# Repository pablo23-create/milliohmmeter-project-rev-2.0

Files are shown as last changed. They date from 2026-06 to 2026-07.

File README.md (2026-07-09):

# Milliohmmeter

A precision resistance measurement device based on STM32 and INA226,
designed for measuring low-resistance components in the range from µΩ to ~5 Ω.

**Status:** PCB manufacturing

## Overview

This device measures ultra-low resistances using a stabilized pulsed current source.
Pulsed measurement mode prevents resistance drift caused by self-heating of the DUT.

**Typical applications:**
- Transformer and motor winding resistance
- Low-resistance shunts
- PCB via and trace resistance
- Connector and contact resistance

## Hardware

| Component | Description |
|---|---|
| STM32F103C8T6 | Main microcontroller - PWM generation, I2C, measurement control |
| INA226 | High-precision differential current/voltage sensor (I2C) |
| Op-Amp + MOSFET | Stabilized current source |
| SSD1306 | 128×64 OLED display |
| Li-ion cell | Main power source |
| TP4056 / BMS | Battery charging and protection |

**PCB:** 4-layer, designed in Altium Designer

## Measurement Principle

1. MCU generates PWM signal → RC filter converts to DC → voltage divider sets reference
2. Op-amp + MOSFET maintain stable test current through DUT
3. INA226 measures voltage drop across DUT via I2C
4. Resistance is calculated: R = U / I
5. Pulsed mode: current applied briefly, measurement taken at peak, then off
   → eliminates thermal resistance drift
6. 4-wire (Kelvin) connection — separate current injection and voltage
   sensing paths eliminate lead and contact resistance.

## Specifications (target)

| Parameter | Value |
|---|---|
| Measurement range | µΩ - 5 Ω |
| Test current | 100 / 500 / 1000 mA |
| Accuracy | < 1% |
| Display | OLED SSD1306 128×64 |
| Power supply | Li-ion, USB-C 5V charging |
| PCB layers | 4 |

## Status Legend

- [x] Complete
- [~] In progress
- [ ] Planned

## Project Status

- [x] Schematic design
- [x] PCB layout (4-layer)
- [~] PCB manufacturing
- [ ] Firmware development
- [ ] Device calibration and testing
- [ ] Enclosure design (SolidWorks)

## Firmware Architecture

**Toolchain:** STM32CubeIDE, HAL, bare-metal (no RTOS)

**Module structure:**

| File | Responsibility |
|---|---|
| `ina226.c/.h` | INA226 init, register config, voltage read via I2C |
| `ssd1306.c/.h` | OLED display driver |
| `current_source.c/.h` | PWM control, current range selection |
| `measurement.c/.h` | Measurement cycle, averaging, zero calibration |
| `main.c` | Init, superloop |

**Measurement cycle (single reading):**
1. Select current range (100 / 500 / 1000 mA) — auto-selected by result
2. Enable PWM → wait settling time (RC filter + OPA333 loop)
3. Read INA226 voltage across DUT
4. Disable PWM
5. R = U / I

**Zero calibration:**
On startup with probes shorted — measure residual offset, store in Flash, subtract from all subsequent readings.

**Firmware development order:**
1. INA226 driver — verify I2C communication and register reads
2. SSD1306 driver — needed for all subsequent debugging
3. PWM configuration — verify current flow with oscilloscope
4. Measurement cycle assembly
5. Auto-range and zero calibration

## Schematic & PCB

[Schematic and PCB layers (PDF)](hardware/Fabrication.pdf)
[Bill of Materials](hardware/fabrication/Bill%20of%20Materials-111.xlsx)
[PCB 3D renders](photos/)

## Author

**runaway**

## License

MIT License

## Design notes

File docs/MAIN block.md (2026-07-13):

# Main Block — MCU, Power Path, Battery, and System Integration

## Scope

This document covers all hardware subsystems not addressed by the
ADC and DC-DC blocks:

- STM32F103C8T6 microcontroller and pin assignment
- Power-on sequencing (discrete latch: AO3401A + BSS138 + BAT54C)
- Digital 3.3 V LDO (LP5907)
- Li-ion battery system (TP4056 charger, DW01A BMS)
- OLED display (SSD1306)
- USB-C input
- PCB layout, mechanical, and thermal integration

Detailed current-source analysis (OPA333, IRLR7843, INA226 filters)
is in the ADC block. Boost converter design (MT3608, inductor,
output filtering) is in the DC-DC block.

Firmware architecture, calibration procedures, and UI screens are
documented separately in the firmware folder.

## STM32F103C8T6 — Pin Assignment

The MCU is the central controller: it generates PWM, drives I2C
peripherals, manages battery monitoring, and holds the power latch
via PB3 to keep the system powered after button release.

### Active Pin Map

| Pin | Function | Direction | Description |
|---|---|---|---|
| PA7 | ADCBAT | Input | Battery voltage via 100k/330k divider |
| PA8 | PWM_OUT | Output | 100 kHz PWM → RC filter → OPA333 reference |
| PA13 | SWDIO | I/O | SWD programming data, 120 Ω series R |
| PA14 | SWCLK | Input | SWD programming clock, 120 Ω series R |
| PC13 | LED_STATUS | Output | "Firmware is alive" indicator LED |
| PD0 | OSC_IN | Input | HSE crystal pin |
| PD1 | OSC_OUT | Output | HSE crystal pin |
| PB0 | STATUS_CHARGE | Input | 5V-USB presence via 47k/82k divider |
| PB3 | PWR_HOLD | Output | Power latch hold — keeps AO3401A gate low  |
| PB2 | BOOT1 | Input | Boot mode select, 100 kΩ pull-down |
| PB6 | SCL | I/O | I2C clock — INA226, SSD1306 |
| PB7 | SDA | I/O | I2C data — INA226, SSD1306 |
| BOOT0  | BOOT0 | Input | Boot mode select, 100 kΩ pull-down |

### PA7 — Battery Voltage Monitoring (ADCBAT)

Battery voltage is divided to fit the 3.3 V ADC range.
Divider: 100 kΩ (top) / 330 kΩ (bottom) from VBAT to GND.

    V_adc = V_bat × R_bottom / (R_top + R_bottom)
          = V_bat × 330k / (100k + 330k)
          = V_bat × 0.767

Range mapping:
- V_bat = 4.2 V (full) → V_adc = 3.22 V (just under 3.3 V ref)
- V_bat = 3.0 V (cutoff) → V_adc = 2.30 V
- V_bat = 2.5 V (BMS cutoff) → V_adc = 1.92 V

Resistor values are chosen high (430 kΩ total) to minimize
dividing current draw from the battery. A 1 µF X7R capacitor
is placed in parallel with the 330 kΩ (R47) for ADC input
buffering and noise rejection on PCB-level switching events
(at 1.2 MHz from MT3608 a smaller cap is insufficient).

ADC sampling timing: programmed to read ADCBAT once per
measurement cycle, with internal averaging configured
to suppress converter switching noise.

### PA8 — PWM_OUT (100 kHz)

PWM frequency is 100 kHz, generated by TIM1_CH1. The signal feeds
the two-stage RC filter documented in the ADC block; the cutoff
frequency (159 Hz) gives ~-40 dB/dec attenuation of the PWM
fundamental.

Duty cycle is set in firmware to select between 100 mA, 500 mA,
and 1000 mA test current ranges. PWM up-count, center-aligned
mode is supported but not strictly required for RC settling at
this frequency.

### PA13 / PA14 — SWD Programming Header (Debug)

SWDIO and SWCLK lines are routed through 120 Ω series resistors.
This serves two purposes:
- Limits inrush current during programming hot-plug events
- Provides a degree of ESD isolation from external programmers
  before the TVS array settles

A 4-pin SWD header (VCC, SWDIO, SWCLK, GND) is placed on the
board edge. In production these pads are unrouted or covered
with conformal coating if no calibrator access is required.

### PC13 — Firmware Status LED

PC13 is used as a heartbeat indicator. The LED is driven low-active
(opens when the firmware loop is running). It is intentionally
NOT a power indicator — power state is visible via the OLED.

Series R = 1 kΩ with a standard red LED (V_F ≈ 2.0 V, I_F ≈ 1 mA):

    I_F = (3.3 - 2.0) / 1k = 1.3 mA

PC13 has the limitation that the LED remains in an
"inconsistent" state during and after reset, but for this
project on-board reset is not a user-visible event — the
100 ms lamp test during boot is acceptable.

### PD0 / PD1 — HSE Crystal (8 MHz)

External 8 MHz HSE crystal drives the PLL to produce the
72 MHz SYSCLK. Crystal load capacitor selection:

    C_load = 2 × (C_L − C_stray) = 2 × (20pF − 5pF) = 30 pF

C17 = C18 = 30 pF (C0G/NP0 dielectric).

HSE is preferred over the internal HSI (±1% accuracy) because
PWM frequency error at ±1% directly maps to test current error
of ±1% — at µΩ measurement levels this dominates accuracy budget.

The crystal is placed close to the OSC pins with a guarded
GND loop around it to prevent 1.2 MHz MT3608 switching noise
from coupling into the oscillator load capacitance.

Note: on the LQFP48 package, PD0/PD1 are the only pins usable
as OSC_IN/OSC_OUT for HSE — they cannot be repurposed as GPIO
in this package. PC14/PC15 are OSC32_IN/OSC32_OUT (LSE, 32.768
kHz) and are unused here since this design has no RTC crystal.

### PB0 — USB Power Detect (STATUS_CHARGE)

PB0 reads the presence of 5 V on USB-C VBUS through a
47 kΩ / 82 kΩ divider.

    V_pb0 = 5.0 × 82k / (47k + 82k) = 5.0 × 0.636 = 3.18 V

This sits below 3.3 V MCU supply and is directly read as a
GPIO high → "USB connected" condition. Reverse-biased action
is not relevant — the divider is unconditionally high impedance
and draws < 100 µA from VBUS even when the device is off.

STATUS_CHARGE is sampled by the firmware to enable battery
voltage display mode on OLED and to detect charging cycles.

### PB3 — Power Latch Hold (PWR_HOLD)

PB3 controls the discrete power latch that keeps the system powered
after the user releases the power button.

**Latch circuit (replaces LTC2954):**
- SW1 (power button) pulls the gate of Q1 (AO3401A, P-channel) to GND
  on press, turning Q1 on and powering the system
- BSS138 (N-channel MOSFET) gate is driven by PB3 via a 1 kΩ
  series resistor; BSS138 source-gate has a 1 kΩ pull-down to GND
- BAT54C dual Schottky diode assembly: one diode from SW1, one from
  BSS138 drain, both feeding Q1 gate — OR-logic, either can hold
  Q1 gate low independently

**Power-on sequence:**
1. User presses SW1 → Q1 gate pulled to GND via SW1 → Q1 conducts
   → MT3608 boost starts → LDOs come up → STM32 boots
2. STM32 firmware initializes → drives PB3 HIGH within first 100 ms
   → BSS138 turns on → holds Q1 gate low via BAT54C
3. User releases SW1 → system remains powered via BSS138 latch

**Power-off sequence:**
1. User presses SW1 again (or firmware initiates shutdown)
2. Firmware drives PB3 LOW → BSS138 turns off
3. Q1 gate released → Q1 turns off → system powers down

This is a fully discrete implementation with no dedicated power
controller IC. Shutdown is always firmware-initiated — there is no
hardware watchdog timeout as with LTC2954. IWDG should be used
as the primary fault recovery mechanism.

### PB2 / BOOT0 — Boot Mode Selection

Both PB2 (BOOT1) and BOOT0 are pulled down to GND via 100 kΩ
resistors, selecting boot from internal flash (BOOT1 = 0,
BOOT0 = 0).

The 100 kΩ value is standard practice when no external boot
source is connected — it draws no DC current except negligible
leakage and pulls the line to a defined state even if the SWD
header is floating.

### PB6 / PB7 — I2C Bus (Standard Mode)

I2C1 operates at Standard Mode (100 kHz) — sufficient for
INA226 (512 conversions/sec) and SSD1306 refresh rates.

Pull-ups are 4.7 kΩ to 3.3 V on both SCL and SDA. Selected
per I2C specification for Standard Mode:

    R_min = (V_cc − V_ol_max) / I_ol = (3.3 − 0.4) / 3mA = 967 Ω
    R_max = 1000 ns / (C_bus + C_pins) ≈ 10 kΩ at 100 kHz

A 4.7 kΩ midpoint value gives clean edges with the
combined bus capacitance of INA226 + SSD1306 + trace
(estimated C_bus < 50 pF).

If firmware debugging reveals timing-dependent issues
during long cable I2C runs to the OLED, switching to Fast
Mode (400 kHz) with 2.2 kΩ pull-ups is a trivial firmware-side
change with no hardware rework required.

## Power-On Controller — Discrete Latch (AO3401A + BSS138 + BAT54C)

The discrete latch replaces a dedicated power controller IC (previously LTC2954).
The MCU cannot latch its own supply directly — once the user releases the button,
VBAT to the boost converter would drop. The latch holds Q1 gate low after boot
until firmware explicitly releases it.

### Sequencing

1. User presses SW1 (≥ ~50 ms debounce in firmware) →
   Q1 (AO3401A) gate pulled to GND via SW1 + BAT54C →
   Q1 conducts → MT3608 boost starts → LP2985 / LP5907 come up → STM32 boots
2. STM32 firmware initializes → drives PB3 HIGH within first 100 ms →
   BSS138 turns on → holds Q1 gate low via BAT54C → latch engaged
3. User releases SW1 → system remains powered via BSS138

### Shutdown

Firmware drives PB3 LOW → BSS138 turns off → Q1 gate released → system powers down.

Power-off is always firmware-initiated. No hardware kill timer exists.
IWDG is the primary fault recovery path — on timeout, reset handler
must drive PB3 LOW before re-entering the main loop or halting.

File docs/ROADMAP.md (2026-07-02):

# Project Documentation Roadmap

## Status Legend
- [x] Complete
- [~] In progress
- [ ] Planned

---

- [x] ADC Block (OPA333, RC-filter, INA226, LP2985)
- [x] DC-DC Block
- [x] Main Block
- [~] Firmware
- [ ] Debug & Testing
- [ ] Future Improvements

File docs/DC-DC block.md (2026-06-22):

# DC-DC Block — MT3608 Boost Converter

## Overview

The DC-DC block steps up the Li-ion battery voltage to a regulated 5.5 V rail,
which feeds downstream LDO regulators:

- **LP5907 3.3 V** — digital supply (STM32, SSD1306)
- **LP2985 5 V** — clean analog supply (OPA333)

Using 5.5 V as the boost target instead of 5.0 V provides 520 mV of headroom
for the LP2985 LDO (dropout ~30 mV) and ensures stable output across the full
Li-ion discharge range (3.0 V – 4.2 V).

The boost output is enabled via Q1 (AO3401A, P-channel MOSFET) controlled
by the EN signal from LTC2954 power-on controller.

## Component Selection

### MT3608 — Boost Controller

| Parameter | Value |
|---|---|
| Topology | Boost (PWM) |
| Switching freq. | 1.2 MHz (internal osc) |
| V_ref (FB) | 0.6 V |
| SW current limit  | 4 A |
| V_in range | 2.0 V – 24 V |
| Package | SOT-23-6 |

1.2 MHz switching frequency is the key design constraint for this project.
All analog measurements (INA226, OPA333 loop) must be protected from
switching noise at this frequency — addressed in the ADC block via
LP2985 isolation and RC filters on INA226 inputs.

### Power Switch — AO3401A (Q1)

P-channel MOSFET controlled by EN signal from LTC2954. Connects VBAT to
the MT3608 input when EN is asserted. R29/R30 (100 kΩ / 100 kΩ) form a
gate voltage divider to ensure reliable turn-on/turn-off.

### Inductor — Bourns SRP5030T-4R7M (L1)

| Parameter | Value |
|---|---|
| Inductance | 4.7 µH |
| I_sat | 6 A |
| I_rms | 5 A |
| DCR | ~27 mΩ |
| Package | 5.0×5.0 mm  |
| Shielding | Yes |

**Why 4.7 µH:**
At 1.2 MHz switching frequency, a smaller inductance is sufficient to
maintain continuous conduction mode (CCM) without excessive ripple current.

Duty cycle at V_in = 3.7 V:

    D = 1 - V_in / V_out = 1 - 3.7 / 5.5 = 0.327

Inductor ripple current:

    dI_L = (V_in x D) / (L x f_sw)
         = (3.7 x 0.327) / (4.7uH x 1.2MHz)
         = 1.21 / 5.64
         = 0.215 A

Ripple dI_L = 215 mA — well within acceptable range.

**Peak current at maximum load (1.2 A):**

    I_peak = I_out x (V_out / (V_in x eta)) + dI_L / 2
           = 1.2 x (5.5 / (3.7 x 0.85)) + 0.108
           = 2.10 + 0.11
           = 2.21 A

I_sat = 6 A provides a safety margin of 2.7x at full load.

**MT3608 current limit verification:**

    I_out_max = (I_sw_max - dI_L / 2) x V_in x eta / V_out
              = (4 - 0.108) x 3.7 x 0.85 / 5.5
              = 2.25 A

1.2 A load is within MT3608 capability with ~1.9x margin.

**Why shielded:**
The SRP5030T series uses a closed magnetic core. This suppresses fringing
flux that would otherwise couple into the L2 solid GND plane and propagate
switching noise across the board — critical given the µΩ-level measurements
in the ADC block.

### Feedback Divider (R2 / R3)

Output voltage is set by a resistive divider on the FB pin:

    V_out = V_ref x (1 + R2 / R3)

With V_ref = 0.6 V and target V_out = 5.5 V:

    R2 / R3 = V_out / V_ref - 1 = 5.5 / 0.6 - 1 = 8.167

Choosing R3 = 100 kΩ:

    R2 = 100k x 8.167 = 816.7 kΩ  →  820 kΩ (E24 series)

Verification:

    V_out = 0.6 x (1 + 820k / 100k) = 0.6 x 9.2 = 5.52 V

Error: +0.4% — acceptable. The 5.5 V target is a headroom rail, not a
precision reference.

> **Note:** Use 1% tolerance resistors for the feedback divider.
> 5% resistors introduce up to ±0.5 V error on V_out — sufficient to
> drop LP2985 input below its minimum or exceed downstream component
> absolute maximum ratings.

### Rectifier Diode — SS36AHL (D1)

| Parameter | Value |
|---|---|
| Type | Schottky |
| V_R (reverse) | 60 V |
| I_F (avg) | 3 A |
| V_F at 1 A | ~0.5 V |
| Package | DO-214AB |

SS36AHL is an improved variant of SS36 with lower reverse leakage current
and better thermal stability. V_R = 60 V exceeds worst-case voltage spikes
(V_out + switching ringing) with margin. Handles full load current of
1.2 A with 2.5x headroom.

### Output Capacitor — C3, 22 µF Ceramic (X8R)

| Parameter | Value |
|---|---|
| Capacitance | 22 µF (nominal) |
| Dielectric | X8R |
| Voltage rating | ≥ 10 V recommended  |

**Why ceramic over electrolytic:**
Ceramic capacitors have very low ESR, which reduces output voltage ripple
at 1.2 MHz. Electrolytic capacitors have significantly higher ESR at this
frequency and are less effective at filtering switching noise.

**DC bias derating:**
Ceramic capacitors lose effective capacitance under DC bias voltage.
The MT3608 datasheet reference design specifies 22 µF nominal but does
not account for derating at operating voltage.

At 5.5 V DC bias, the 22 µF X8R capacitor degrades to approximately
~4.4 µF effective capacitance (~80% loss).

Impact on output voltage ripple at maximum load (1.2 A):

    dV_out = (I_out x D) / (C_eff x f_sw)
           = (1.2 x 0.327) / (4.4uF x 1.2MHz)
           = 0.392 / 5.28
           = 74.8 mV

For comparison, at nominal 22 µF without derating:

    dV_out = (1.2 x 0.327) / (22uF x 1.2MHz) = 14.9 mV

Derating increases ripple by 5x. At 1.2 A load this is significant —
74.8 mV ripple on the 5.5 V rail reduces the effective headroom for
LP2985 from 520 mV to ~445 mV under worst case. LP2985 (PSRR = 75 dB
at 1.2 MHz) attenuates this ripple by ~5600x before it reaches the
analog supply, so measurement accuracy is not compromised. However,
adding a second output capacitor is recommended.

**Recommended fix — add second 100 µF X8R in parallel:**

    C_eff_total = 4.4 + 19 = 23.4 uF
    dV_out = (1.2 x 0.327) / (23.4uF x 1.2MHz) = 13,9 mV

Ripple reduced by 2x with minimal board area impact (same footprint).

**INA226 averaging as supplementary ripple mitigation:**
The INA226 ADC supports hardware averaging (up to 1024 samples).
This is used as a supplementary measure alongside output capacitor
filtering — averaging reduces the effect of residual switching noise
on voltage measurements, improving effective resolution at µΩ levels.
Averaging does not replace output filtering but complements it.

X8R was selected over X5R/X7R for better DC bias stability.

### Input Capacitor — C1, 22 µF Ceramic

C1 provides local decoupling at the MT3608 input, stabilizing V_in
during switching transients and reducing input ripple current drawn
from the battery.

## PCB Layout Considerations

The MT3608 switching loop carries high di/dt currents at 1.2 MHz.
Poor layout directly causes noise coupling into analog measurements.

**Critical loop:** MT3608 SW pin → L1 → D1 → C3 → GND → MT3608 GND

- Keep this loop as small as possible on L1 signal layer
- Place C3 immediately adjacent to D1 cathode and MT3608 output
- SW node trace must be short and wide — it carries full inductor current
- Do not route sensitive analog signals parallel to the SW node trace

**Component placement:**
The DC-DC block (Q1, U2, L1, D1) is located in the top-left corner of
the board. The analog measurement block (OPA333, INA226) is located on
the right edge, with STM32 between them. This physical separation
minimizes direct coupling of switching noise into the analog section.

**GND plane (L2):**
The board uses a single solid GND plane on L2 without a separate analog
ground pour. This is acceptable given the physical separation between
the DC-DC and analog blocks — switching return currents follow the
path of least impedance back to Q1/U2 and do not pass through the
analog measurement zone.

The shielded inductor (SRP5030T) prevents magnetic flux from coupling
into the GND plane beneath it.

**LP2985 placement:**
LP2985 sits between the 5.5 V boost rail and the OPA333 analog supply.
Its 75 dB PSRR at 1.2 MHz is the primary isolation barrier for the
analog block. Placement close to OPA333 minimizes post-regulation
trace length and reduces pickup area.

## Power Budget

| Rail | Consumer | Estimated Current |
|---|---|---|
| 3.3 V (LP5907) | STM32 | ~50 mA |
| 3.3 V (LP5907) | SSD1306 OLED | ~20 mA |
| 5 V (LP2985) | OPA333 | ~5 mA |
| 5.5 V | LDO quiescent + misc | ~5 mA |
| 5.5 V | Current source (DUT) | ~1100 mA (peak) |
| **Total** | | **~1180 mA** |

Peak load occurs only during measurement pulses (~100 ms). Average
current draw is significantly lower due to the pulsed measurement mode.

MT3608 maximum deliverable output current at V_in = 3.7 V:

    I_out_max = (I_sw_max - dI_L / 2) x V_in x eta / V_out
              = (4 - 0.108) x 3.7 x 0.85 / 5.5
              = 2.25 A

1.2 A peak load leaves ~1.05 A margin.

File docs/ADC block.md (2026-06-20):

# ADC Block - Technical Design Document

## OPA333 - Current Source Control

OPA333 was selected for its near-zero input offset voltage (zero-drift),
rail-to-rail input/output, and wide input voltage range.
These characteristics are critical for precise reference voltage
reproduction at the op-amp input, which directly controls
the test current stability.

## PWM-to-Reference Conversion (RC Filter)

MCU generates PWM signal which is converted to a stable DC reference
voltage for the op-amp via a two-stage RC filter.

**Filter parameters (each stage):**
- R = 10 kΩ, C = 100 nF
- Cutoff frequency: f = 1/(2π·R·C) ≈ 159 Hz

Two identical cascades do not shift the cutoff frequency —
it remains at 159 Hz — but increase the roll-off slope
from -20 dB/dec to -40 dB/dec, significantly improving
PWM ripple suppression at 100 kHz.

**Settling time:**
- Single stage: 5τ = 5·RC = 5 ms
- Two stages: approximately 12–13 ms (empirical ~2.5× factor)

PWM frequency of 100 kHz ensures fast RC settling,
allowing pulsed measurement duration to be reduced if needed
by increasing PWM frequency — shorter settling time means
shorter minimum pulse width.

## Voltage Divider (Post-Filter)

A 10:1 voltage divider is placed after the two-stage RC filter.

This serves two purposes:
- Scales the reference voltage to the required input range of OPA333
- Reduces residual PWM ripple by an additional factor of 10,
  providing a clean reference for the op-amp

A stable reference at OPA333 input ensures the op-amp correctly
drives the MOSFET gate, keeping the test current stable
during pulsed measurements.

## OPA333 + IRLR7843 - Feedback Stability

IRLR7843 gate capacitance (Ciss = 4380 pF) combined with OPA333
open-loop output impedance (~5 kΩ) and unity-gain bandwidth (350 kHz)
would cause high-frequency oscillation without compensation.

**Isolation resistor R9:**
Placed between op-amp output and MOSFET gate to isolate
capacitive load from the feedback loop.

R9 = 1/(2π·F·C) = 1/(2π·350kHz·4380pF) ≈ 103 Ω → selected 120 Ω
(within recommended range 20–120 Ω)

**Feedback filter R11 + C14:**
R11 (feedback resistor) selected at 10 kΩ to avoid loading the op-amp
(recommended range: 10 kΩ – 100 kΩ).

C14 calculated for optimal damping:
C = Ciss × (Ro + Riso) / Rf = 4380 × (5000 + 120) / 10000 ≈ 2243 pF
→ selected nearest standard value: 2.2 nF (C0G/NP0 for stability)

Notes: 
- R11 value on schematic to be updated to 10 kΩ.
- The OPA333 and IRLR7843 combination itself works very slowly and is only suitable for linear modes, which is exactly what we are talking about.

## INA226 - Voltage Measurement

INA226 measures voltage drop directly across the DUT.
Test current is fixed by the OPA333 control loop (via PWM reference),
so resistance is calculated as R = U / I.

INA226 supports 4-wire (Kelvin) connection — separate force and sense
lines eliminate contact and lead resistance from the measurement,
which is essential for µΩ-level accuracy.

Differential input traces (VIN+ and VIN−) are routed as short as
possible following differential pair rules (tight coupling)
for common-mode noise rejection.

## INA226 - Input Filter (R8, R22, C21)

MT3608 DC-DC converter operates at 1.2 MHz. The measurement shunt
sits on this supply line, making INA226 inputs susceptible to
switching noise at 1.2 MHz — which coincides with harmonics of
INA226 internal ADC sample rate (500 kHz ±30%, harmonics at
1 MHz, 1.5 MHz...).

Per INA226 datasheet recommendation:
- R8, R22 = 10 Ω (series input resistors)
- C21 = 1 µF (differential filter capacitor)

This filter attenuates switching noise above 1 MHz before it
reaches INA226 inputs, preventing ADC corruption during measurement.

## LP2985 - Analog Power Supply

LP2985 (5V version) provides a clean, isolated supply for OPA333
and analog circuitry, separated from the noisy DC-DC boost converter rail.

Selected for:
- PSRR: ~75 dB at low frequencies
- Output noise: ~30 µV RMS
- Dropout voltage: ~30 mV at 150 mA
- Output accuracy: ±0.5%
- Minimal external components

5V version selected to match IRLR7843 gate drive requirements.
OPA333 supply quality directly affects output signal integrity —
any supply noise appears as reference error and impacts
current source stability.

## Pulsed Measurement Mode

Continuous current flow causes resistive heating of the DUT,
leading to resistance drift during measurement.

Pulsed mode applies current for ~100 ms per measurement cycle.
This allows multiple consecutive measurements without thermal drift
of the DUT and PCB traces.

## 4-Layer PCB

4-layer stackup was chosen for compactness, routing simplicity,
and noise immunity.

Stackup: L1 (signal) / L2 (solid GND) / L3 (power) / L4 (signal/GND)

Dedicated GND and power planes isolate signal traces from supply
currents. This is critical during pulsed measurements — high di/dt
events on power layers do not couple into the measurement signal
path, reducing transient-induced errors.

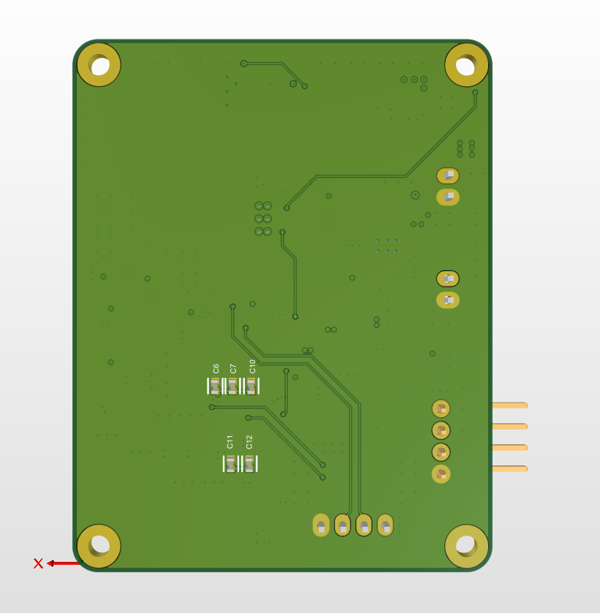
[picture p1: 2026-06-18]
photos/PCB3DLOOKBACK.png

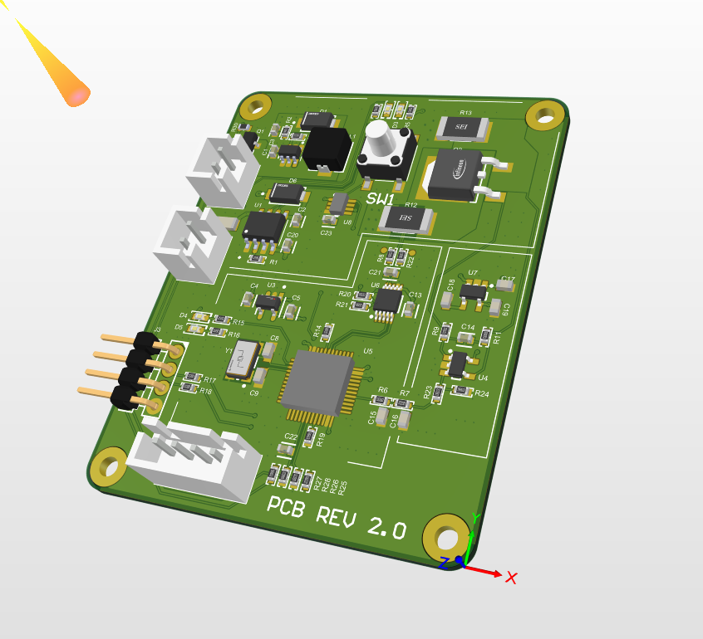
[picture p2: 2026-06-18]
photos/PCB3DVIEW.png

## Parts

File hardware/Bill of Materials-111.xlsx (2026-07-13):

Comment | Description | Designator | Footprint | LibRef | Quantity
 | C0603 22uF X8R 30ppm/°C 5.00% 10 V, C0603 1uF X8R 30ppm/°C 5.00% 50 V, C0603 100pF X8R 30ppm/°C 5.00% 50 V, C0603 100uF X8R 30ppm/°C 5.00% 10 V | C1, C3, C4, C5, C6, C7, C10, C11, C12, C13, C14, C21, C22, C24, C25, C26 | FP-C0603C-CF-MFG | CMP-2006-03086-2 | 16
22uF | C0603 10uF X8R 30ppm/°C 5.00% 50 V | C2 | FP-C0603C-CF-MFG | CMP-2006-03086-2 | 1
22pF |  | C8, C9 | CAPC1608X90X35NL15T15 | CMP-2006-04271-1 | 2
100nF C0G |  | C15, C16 | CAPC1608X87X35LL15T15 | CMP-2006-03842-1 | 2
1UF X7R |  | C17 | CAPC1608X87X45LL20T05 | CMP-2006-00004-1 | 1
10NF X7R |  | C18 | CAPC1608X87X35LL15T15 | CMP-2006-03842-1 | 1
2.2UF X7R |  | C19 | CAPC1608X87X45LL20T05 | CMP-2006-00004-1 | 1
10uF | C0603 10uF X8R 30ppm/°C 5.00% 50 V | C20 | FP-C0603C-CF-MFG | CMP-2006-03086-2 | 1
SS36ALH | 3A, 60V, Schottky Rectifier | D1, D6 | SODFL5226X100N | SS36ALH | 2
Blue | LED RED CLEAR CHIP SMD | D2, D4 | LED 0603_1608 YELLOW | LSM0603472V | 2
Red | LED RED CLEAR CHIP SMD | D3, D5 | LED 0603_1608 YELLOW | LSM0603472V | 2
BAT54C,215 | DIODE ARRAY SCHOTTKY 30V SOT23 | D7 | FP-SOT23-MFG | CMP-14398-000007-1 | 1
B2B-XH-A(LF)(SN) | CONN HEADER VERT 2POS 2.5MM | J1, J2 | JST XH B2B-XH-A | B2B-XH-A(LF)(SN) | 2
M20-9960445 | CONN HEADER R/A 4POS 2.54MM | J3 | HARWIN M20-9960445 | M20-9960445 | 1
B4B-XH-A(LF)(SN) | CONN HEADER VERT 4POS 2.5MM | J4 | JST XH B4B-XH-A | B4B-XH-A(LF)(SN) | 1
4.7 µH | FIXED IND 4.7UH 4.6A 53 MOHM SMD | L1 | BOURNS SRP5030T | SRP5030T-4R7M | 1
AO3401A | P-Channel MOSFET, 30 V, 4 A, -55 to 150 degC, 3-Pin SOT-23-3L, RoHS, Tape and Reel | Q1 | AO-SOT-23-3L_V | CMP-2000-05778-1 | 1
IRLR7843TRPBF | MOSFET N-CH 30V 161A DPAK | Q2 | FP-PG-TO252-3-MFG | CMP-32901-000143-1 | 1
BSS138 | MOSFET N-CH 50V 220MA SOT-23 | Q3 | FP-318-08-IPC_B | CMP-07173-000101-1 | 1
5 kOhms | RES 115K OHM 1% 1/10W 0603 | R1 | KOA RES RK73 RN73 0603_1608 | RK73H1JTTD1153F | 1
820 kOhms | RES 820K OHM 1% 1/10W 0603 | R2 | KOA RES RK73 RN73 0603_1608 | RK73H1JTTD1153F | 1
100 kOhms | RES 100K OHM 1% 1/10W 0603, RES 100 KOHM 1% 1/10W 0603, RES 10 KOHM 1% 1/10W 0603, RES 115K OHM 1% 1/10W 0603 | R3, R14, R19, R24, R27 | KOA RES RK73 RN73 0603_1608 | RK73H1JTTD1153F | 5
1 kOhms | RES 115K OHM 1% 1/10W 0603 | R4, R5, R15, R16 | KOA RES RK73 RN73 0603_1608 | RK73H1JTTD1153F | 4
10 kOhms | RES 10 KOHM 1% 1/10W 0603, RES 1 KOHM 1% 1/10W 0603 | R6, R7, R11 | KOA RES RK73 RN73 0603_1608 | RK73H1JTTD1153F | 3
10 Ohms | RES 10 OHM 1% 1/10W 0603 | R8, R22 | KOA RES RK73 RN73 0603_1608 | RK73H1JTTD1153F | 2
120 Ohms | RES 10 OHM 1% 1/10W 0603, RES 120 OHM 1% 1/10W 0603 | R9, R17, R18 | KOA RES RK73 RN73 0603_1608 | RK73H1JTTD1153F | 3
RC1206FR-10750RL |  | R10 | RESC3116X65X40LL10T20 | CMP-2003-04964-1 | 1
0.01 Ohms | Foil on Ceramic Current Sensing Chip Resistor 10mΩ ±1% 2W 2512 AEC Qualified | R12 | FP-CSRF2512-IPC_B | CMP-26527-001250-1 | 1
0.1 Ohms | Foil on Ceramic Current Sensing Chip Resistor 100mΩ ±1% 2W 2512 AEC Qualified | R13 | FP-CSRF2512-IPC_B | CMP-26527-001250-1 | 1
10 k | RES 10KOHM 1% 1/10W 0603 | R20, R21 | KOA RES RK73 RN73 0603_1608 | RK73H1JTTD1153F | 2
1 МOhms | RES 10 KOHM 1% 1/10W 0603 | R23 | KOA RES RK73 RN73 0603_1608 | RK73H1JTTD1153F | 1
47 kOhms | RES 115K OHM 1% 1/10W 0603 | R25 | KOA RES RK73 RN73 0603_1608 | RK73H1JTTD1153F | 1
82 kOhms | RES 115K OHM 1% 1/10W 0603 | R26 | KOA RES RK73 RN73 0603_1608 | RK73H1JTTD1153F | 1
330 kOhms | RES 115K OHM 1% 1/10W 0603 | R28 | KOA RES RK73 RN73 0603_1608 | RK73H1JTTD1153F | 1
100 kOhms | RES 115K OHM 1% 1/10W 0603 | R29, R30 | RES_ERJU03J3R0V | RK73H1JTTD1153F | 2
1 kOhms | RES 2K OHM 1% 1/10W 0603 | R31, R32 | RES_ERJU03J3R0V | RK73H1JTTD1153F | 2
430152070826 | Switch Tactile N.O. SPST Round Button Gull Wing 0.05A 12VDC 500000Cycles 2.55N SMD Reel | SW1 | 430152070826 | CMP-1452-00005-5 | 1
TP4056 | Complete single cell Li-Ion battery with a constant current / constant voltage linear charger | U1 | SOP127P600X175-9N | TP4056 | 1
MT3608 | High Efficiency 1.2MHz2A Step Up Converter | U2 | SOT95P280X145-6N | MT3608 | 1
LP5907-3.3 | None | U3 | FP-DBV0005A-IPC_A | CMP-04917-000179-2 | 1
OPA333AIDBVT | 17 uA, MicroPower, Precision, Zero Drift CMOS Operational Amplifier, 1.8 to 5.5 V, -40 to 125 degC, 5-pin SOT23 (DBV5), Green (RoHS & no Sb/Br) | U4 | DBV0005A_M | CMP-0272-00841-3 | 1
STM32F103C8T6 | ARM Cortex-M3 32-bit MCU, 64 KB Flash, 20 KB Internal RAM, 37 I/Os, 48-pin LQFP, -40 to 85 degC, Tray | U5 | STM-LQFP48_L | CMP-0237-00215-3 | 1
INA226AIDGST | High-Side Measurement, Bi-Directional Current / Power Monitor with I2C Interface, 2.7 to 5.5 V, -40 to 125 degC, 10-pin SOP (DGS10), Green (RoHS & no Sb/Br) | U6 | DGS0010A_L | CMP-0704-00057-2 | 1
LP2985-50DBVR | Single Output Low Noise LDO, 150 mA, Fixed 5 V Output, 1.5% Tolerance, 2.2 to 16 V Input, Low IQ, 5-Pin SOT-23 (DBV), -40 to 125 degC, Green (RoHS & no Sb/Br), Tape and Reel | U7 | DBV0005A_M | CMP-0758-00084-2 | 1
ABM3BAIG-8.000MHZ-1Z-T | CRYSTAL 8.0000MHZ 18PF SMD | Y1 | FP-ABM3BAIG-MFG | CMP-27762-004085-1 | 1

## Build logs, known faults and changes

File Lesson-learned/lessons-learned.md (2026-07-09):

# Lessons Learned — Milliohmmeter Project

A running log of mistakes, wrong turns, and how they were fixed.
Format: what went wrong → why → what was done instead.

## Rev 1 → Rev 2

### LTC2954 — Replaced with Discrete Latch

**What went wrong:**
LTC2954 was used as a push-button power-on controller. The IC works,
but it is expensive, requires careful external component selection
(PDT capacitor for timing), and adds unnecessary complexity for a
simple latched power path.

**Why it was a problem:**
- Higher cost and lower availability compared to discrete solution
- PDT timing capacitor requires calculation and tuning
- Overkill for a device that only needs: press-to-on, firmware-controlled-off

**What was done instead:**
Replaced with a discrete latch using three common components:
- AO3401A — P-channel MOSFET, main power switch (same as before)
- BSS138 — N-channel MOSFET, holds AO3401A gate low after boot
- BAT54C — dual Schottky diode assembly, OR-logic between SW1 and BSS138

MCU drives PB3 HIGH after boot to engage the latch.
Power-off: firmware drives PB3 LOW → system shuts down.

**Trade-off accepted:**
No hardware kill timer (LTC2954 had one). IWDG is now the only
fault recovery path. On IWDG timeout the reset handler must drive
PB3 LOW explicitly, otherwise the system reboots in a loop.

---

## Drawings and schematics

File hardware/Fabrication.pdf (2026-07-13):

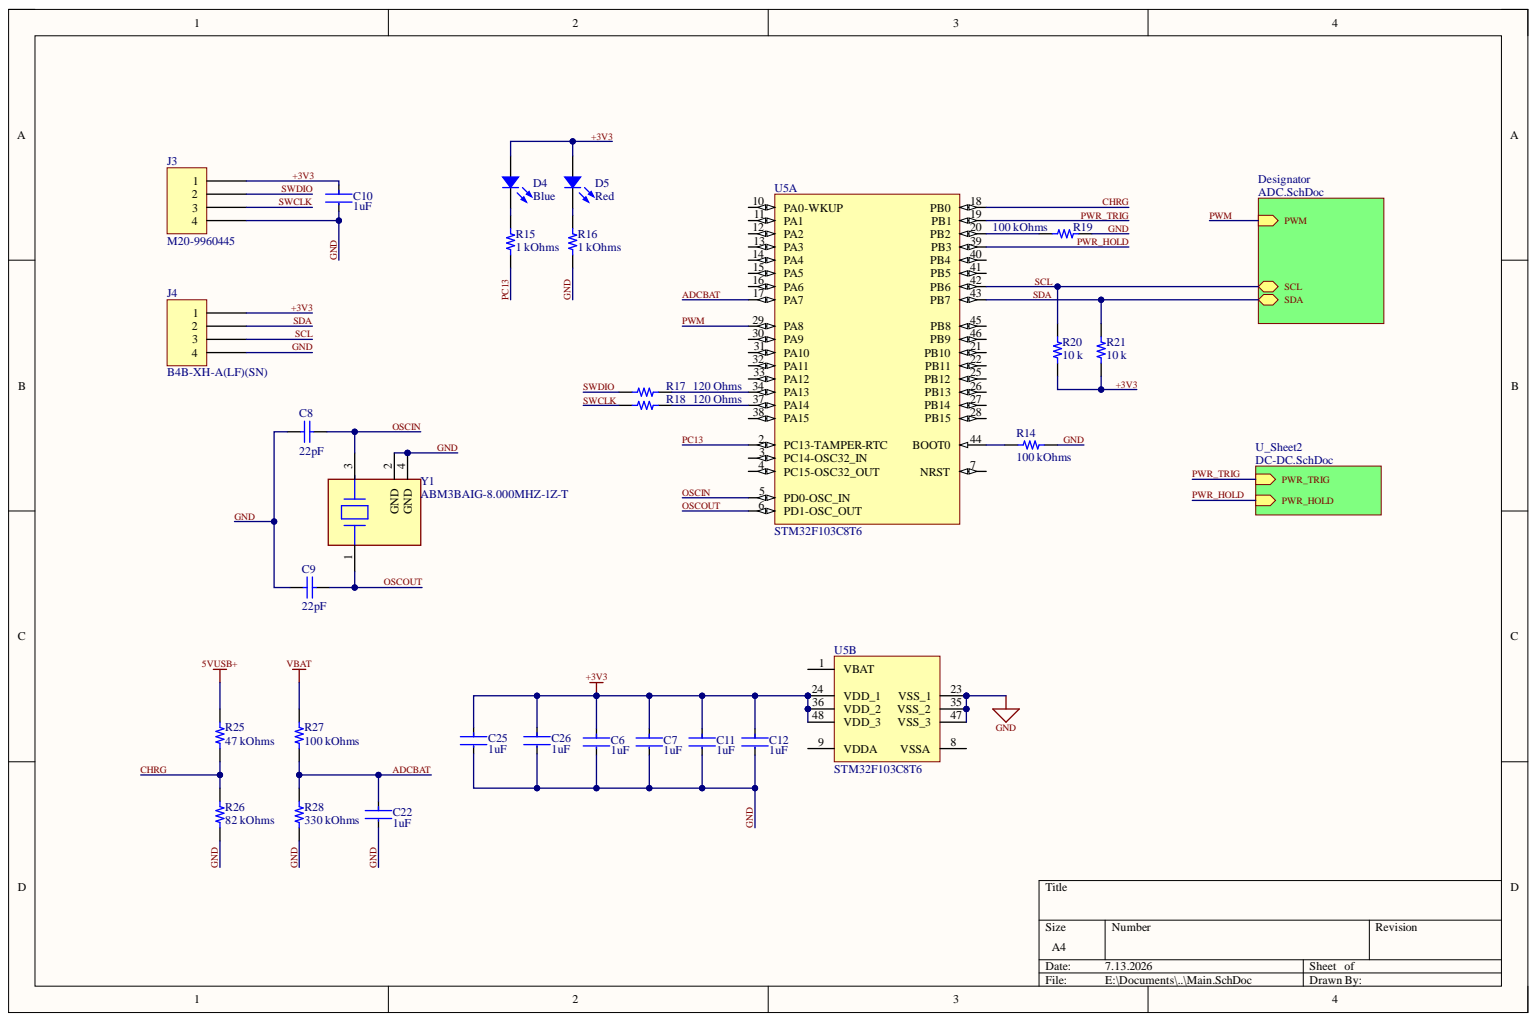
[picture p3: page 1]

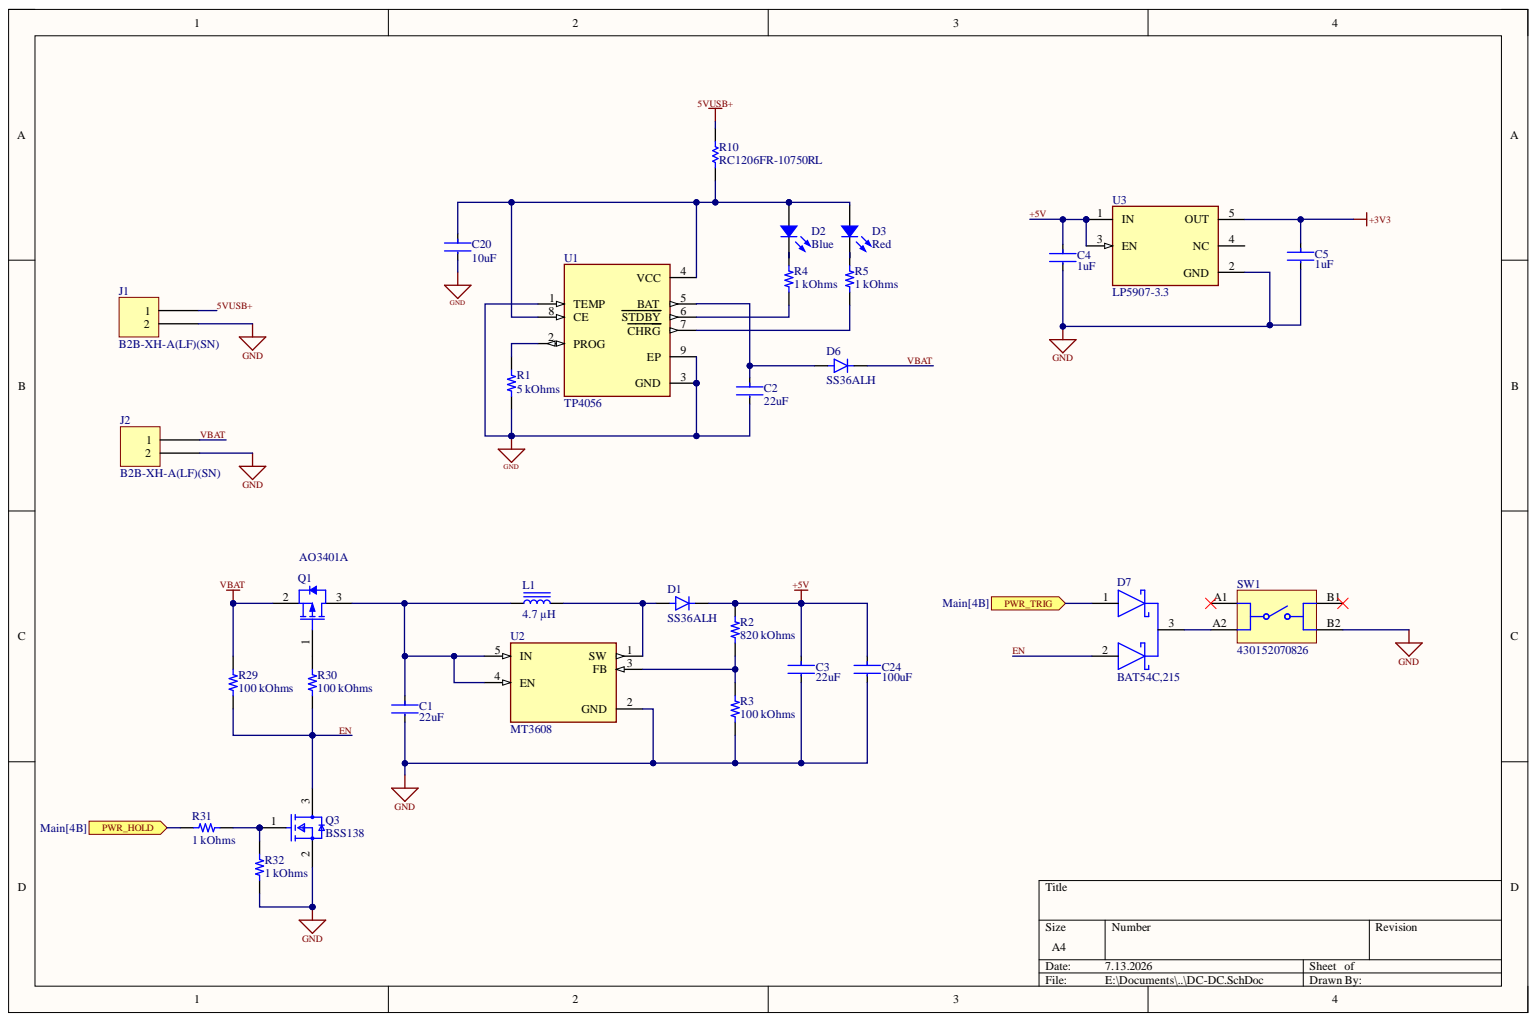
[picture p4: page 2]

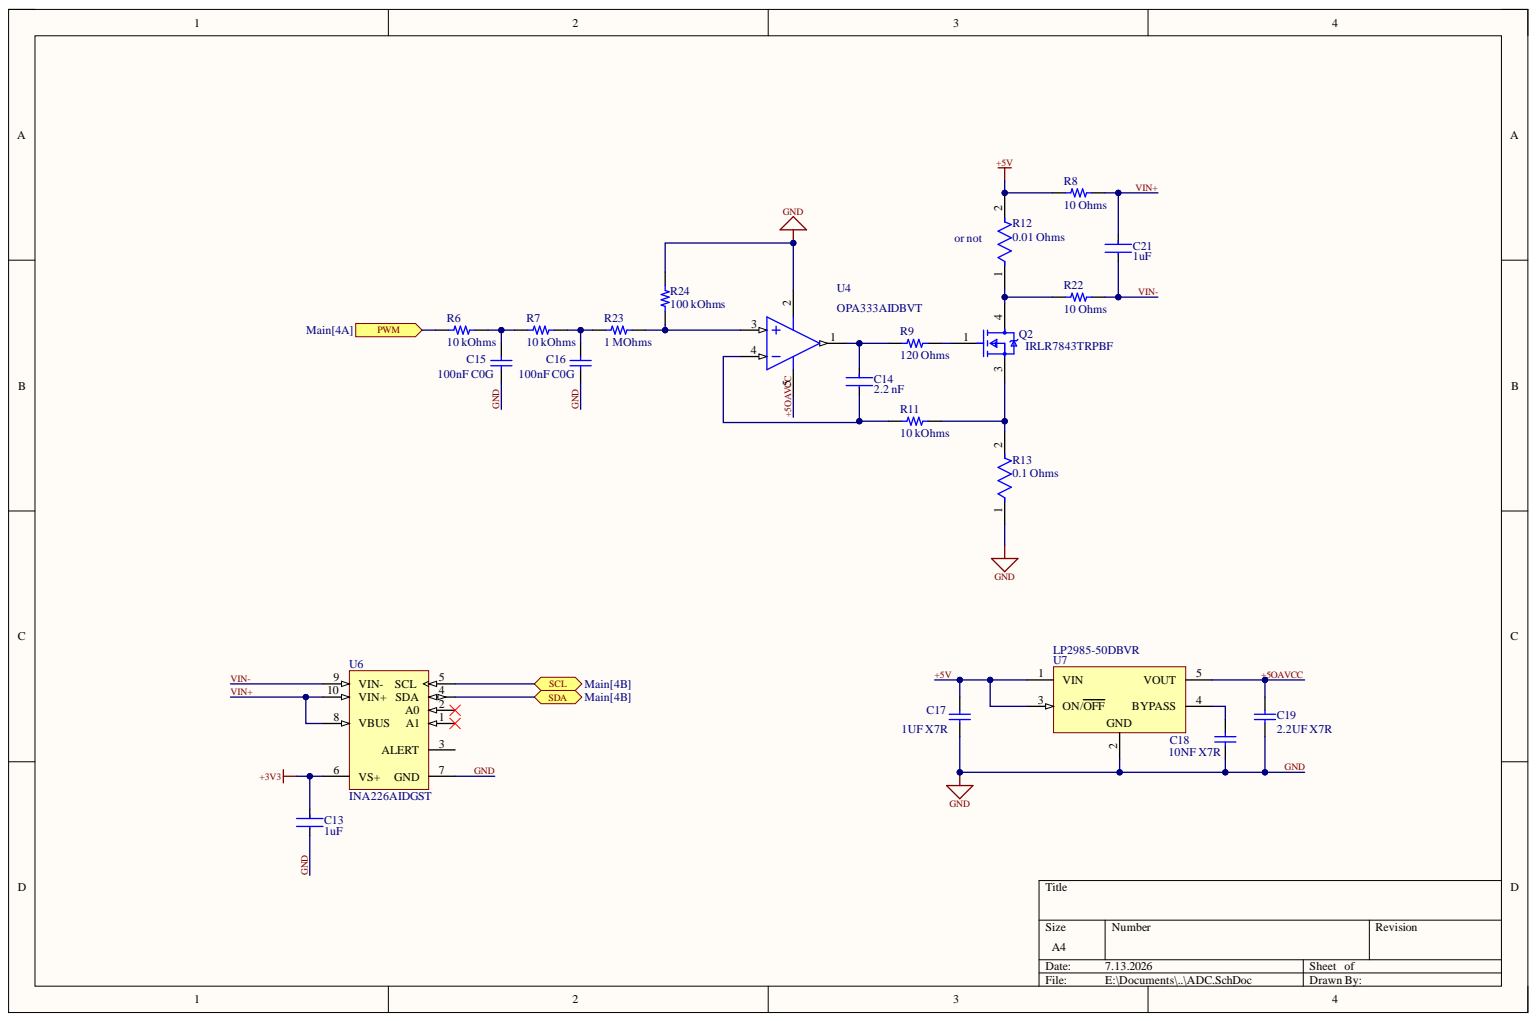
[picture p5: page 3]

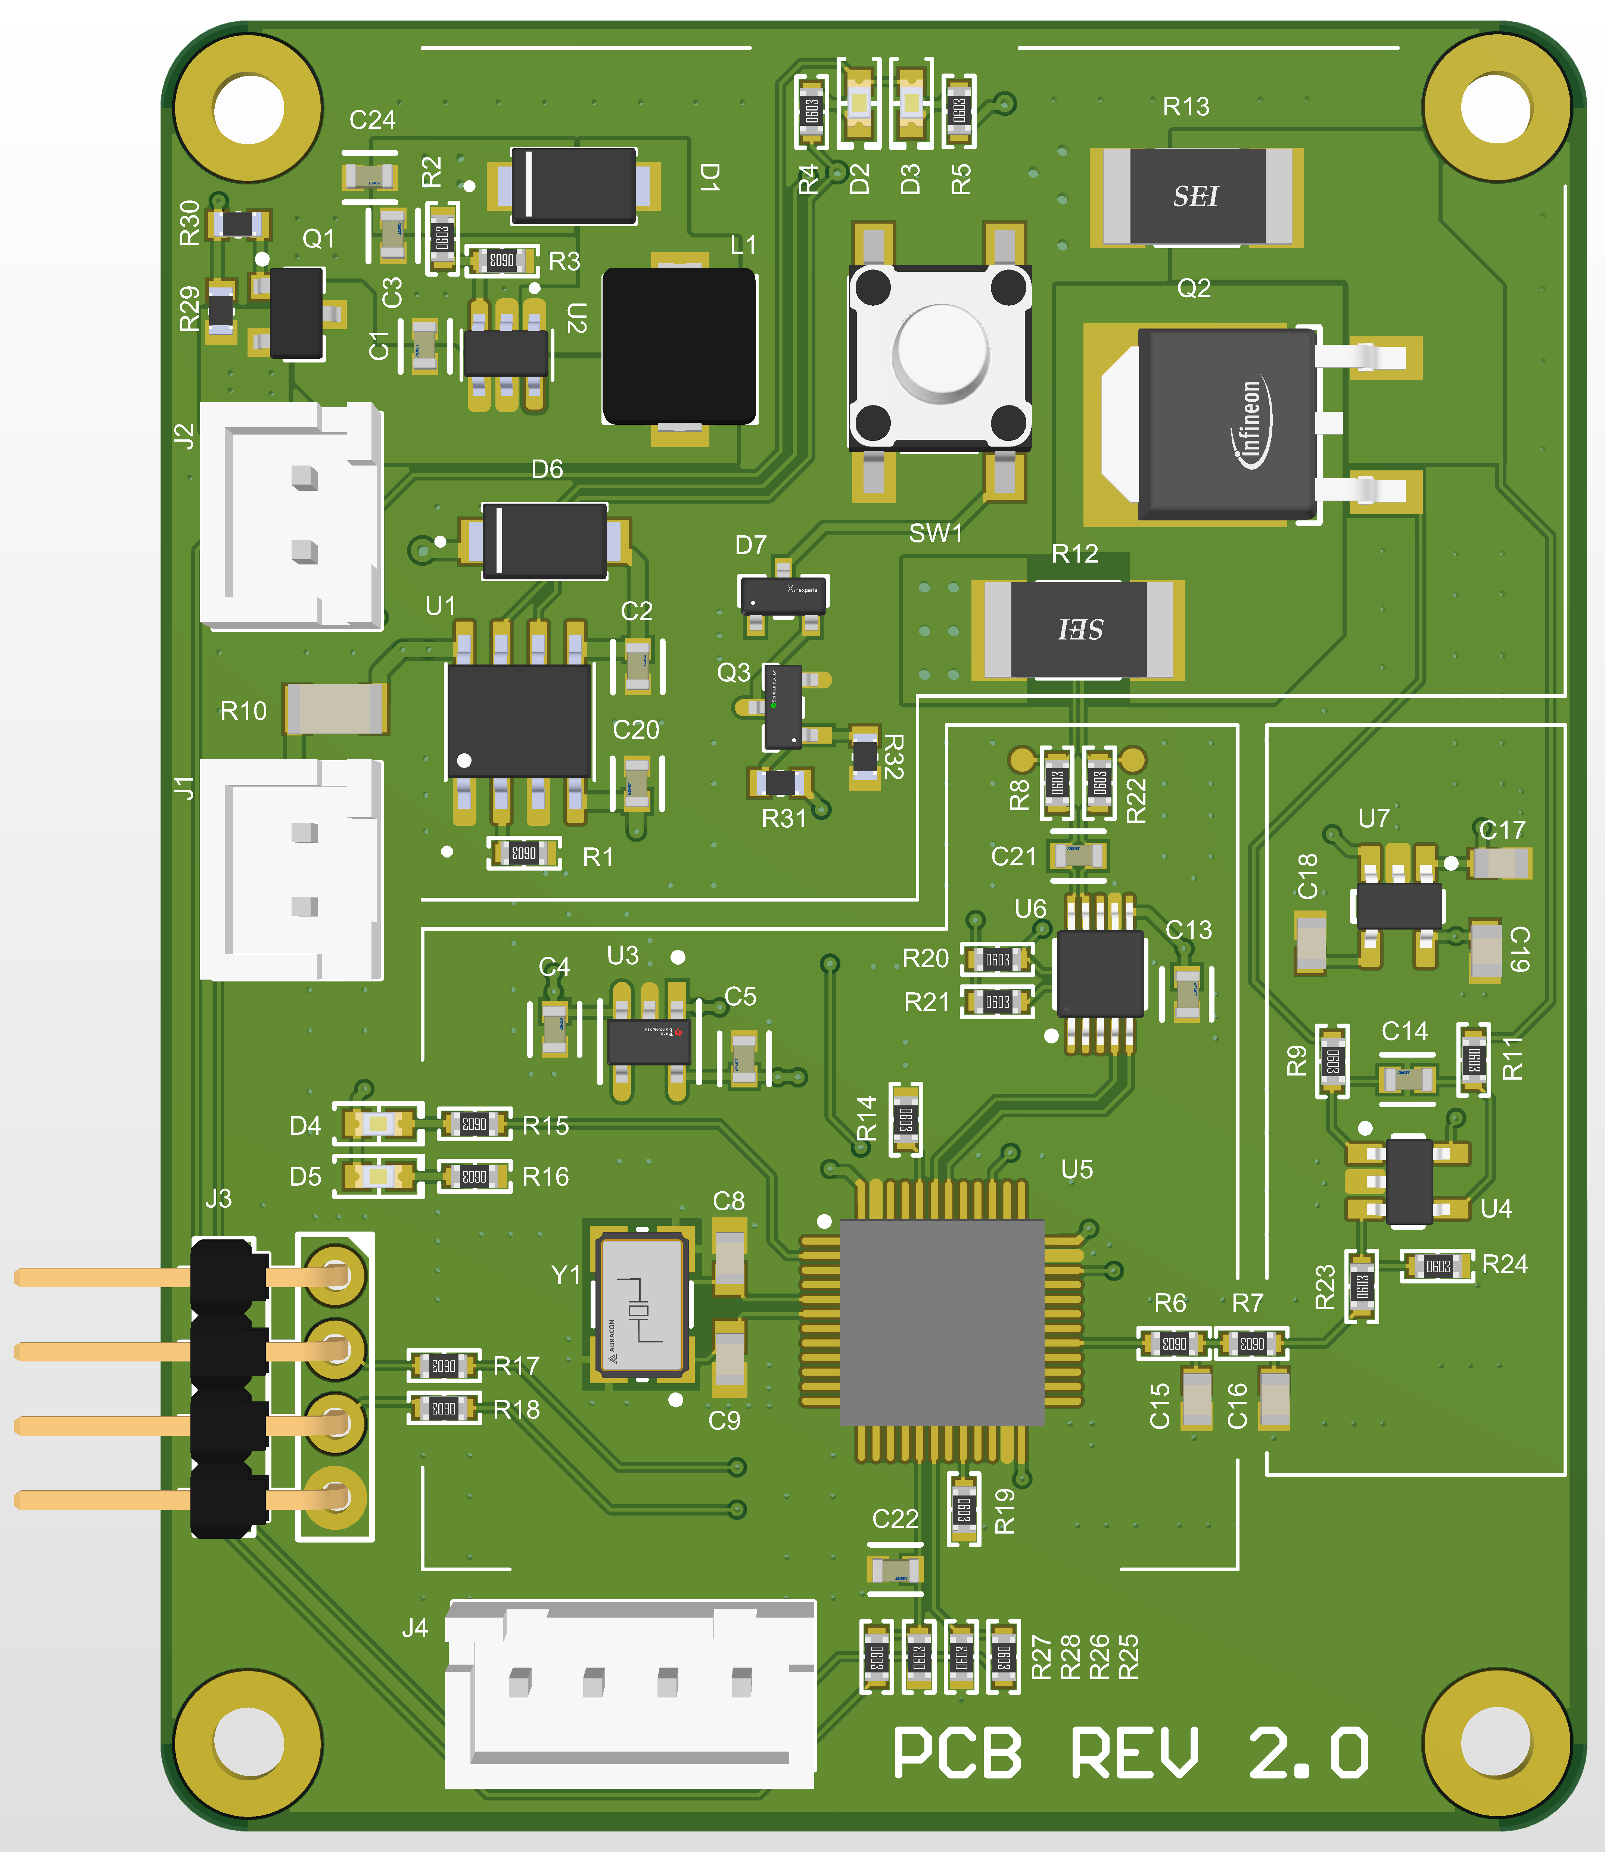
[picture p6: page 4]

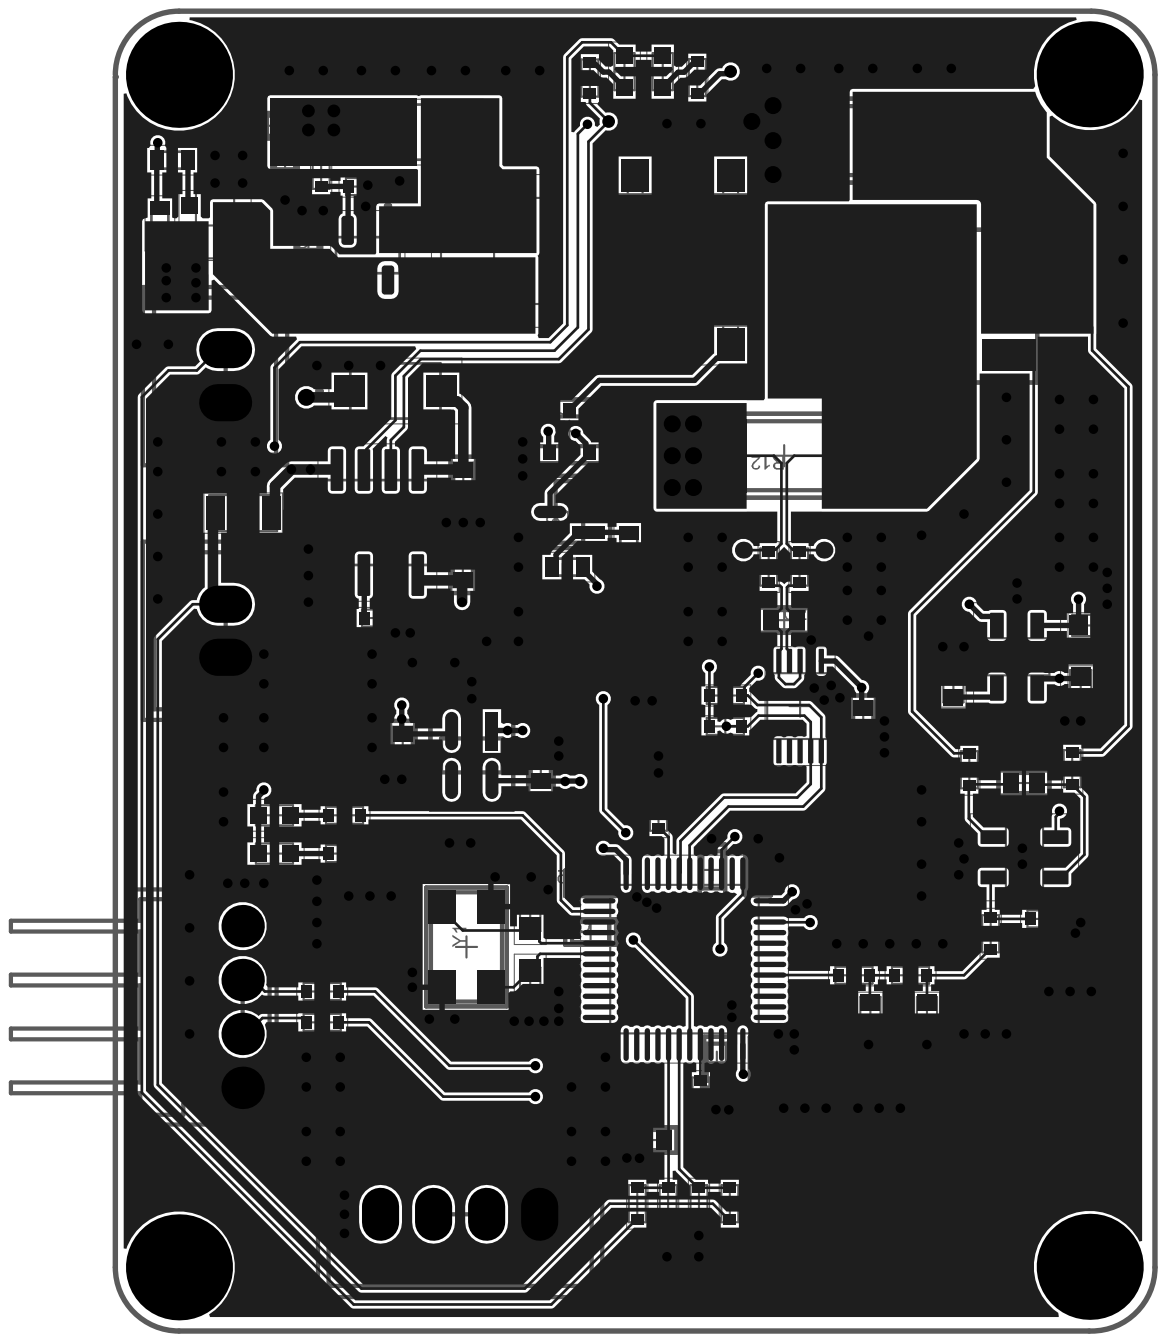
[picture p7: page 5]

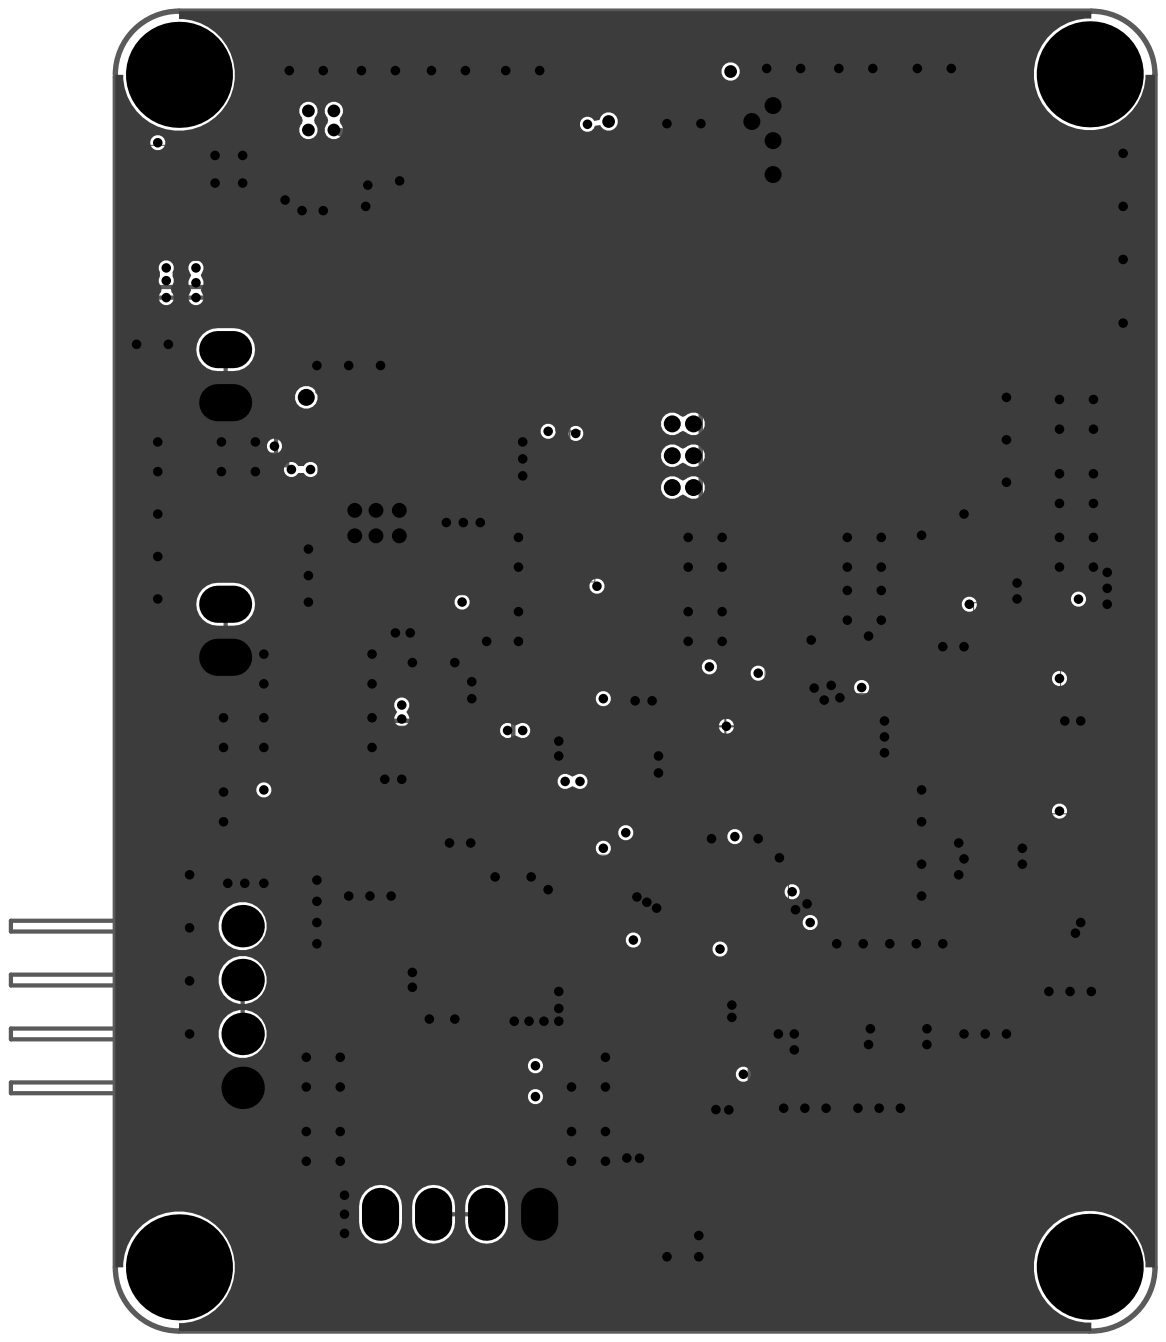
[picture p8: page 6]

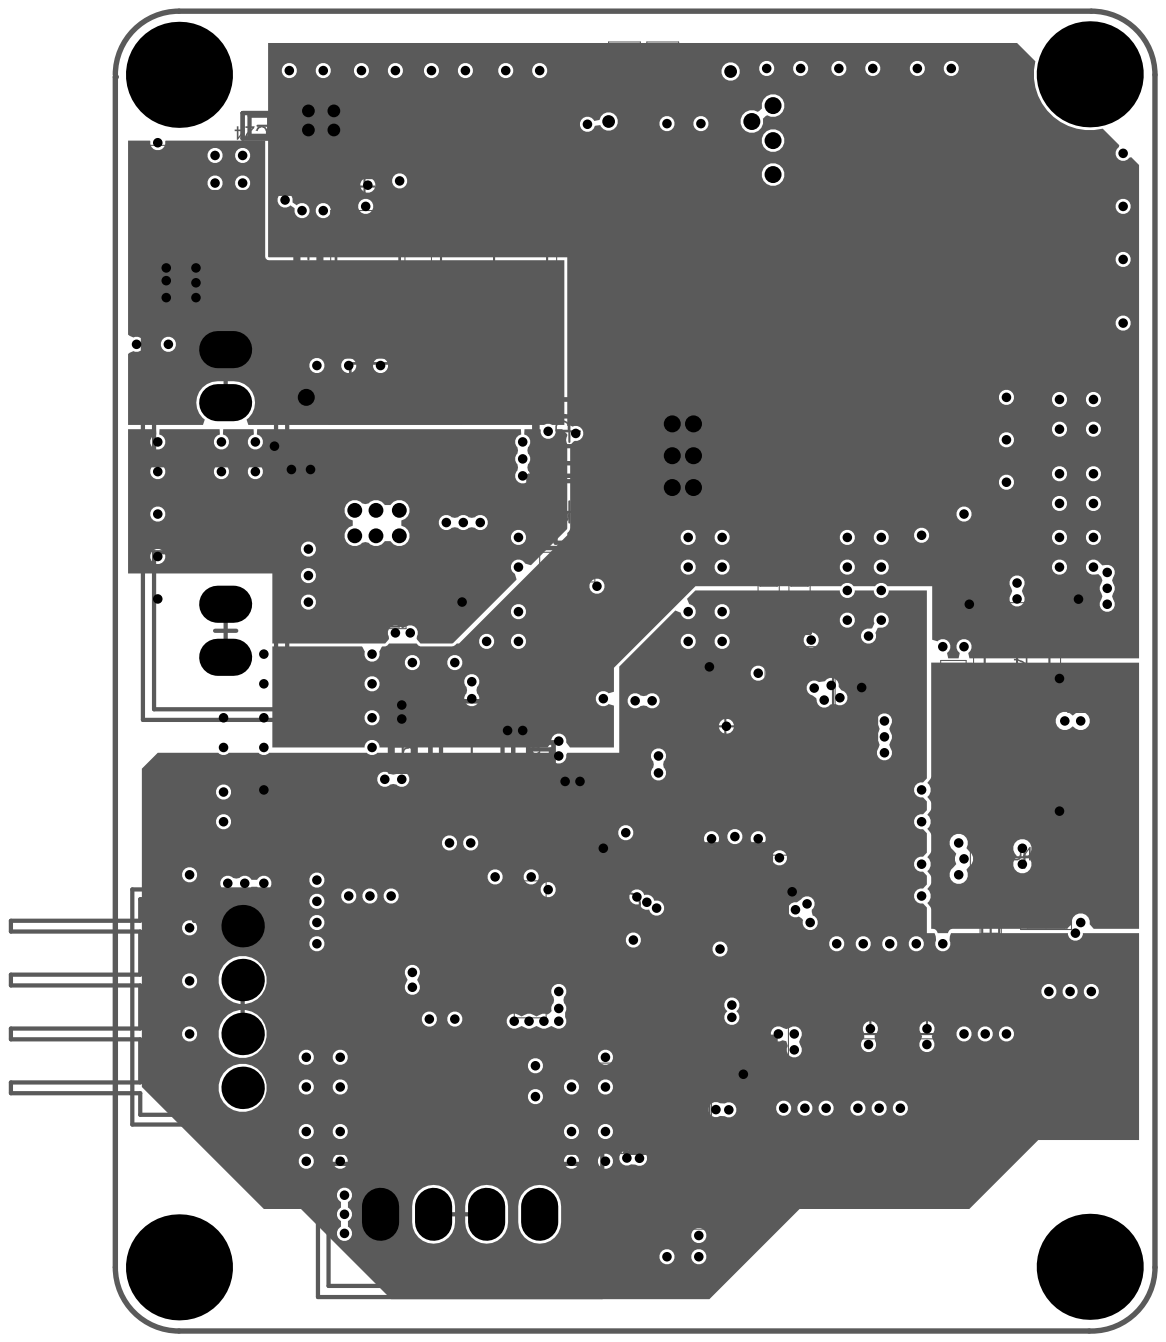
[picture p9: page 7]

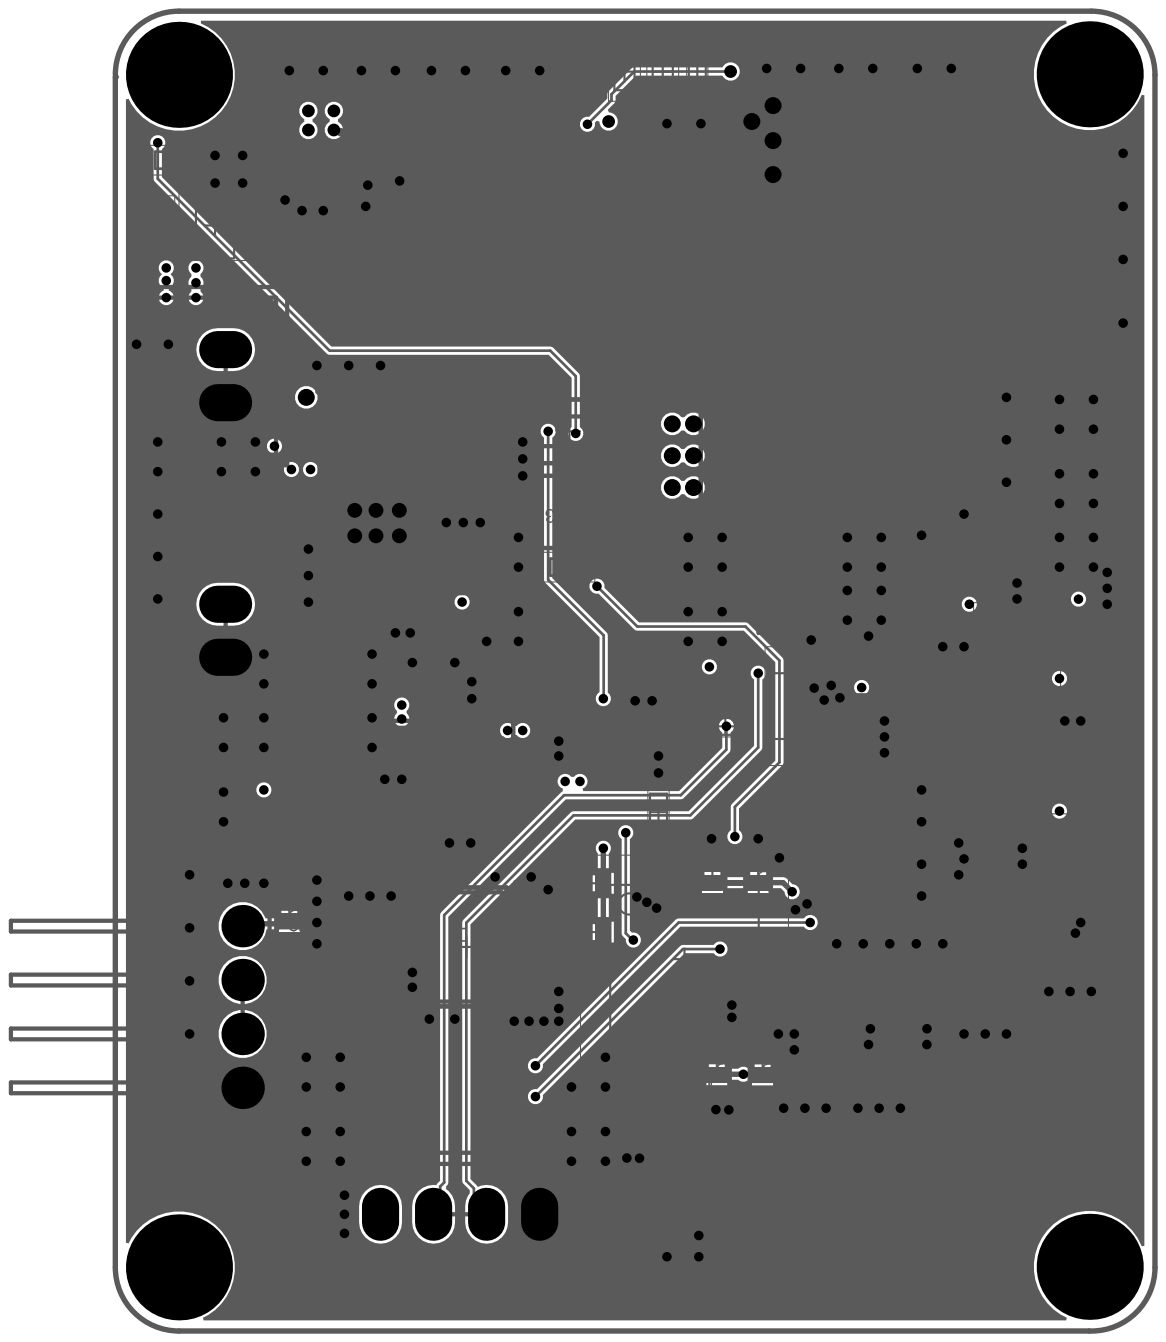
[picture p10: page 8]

# Board Stack Report

Stack Up | Layer Stack
Layer | Board Layer Stack | Name | Material | Thickness | Constant | Color

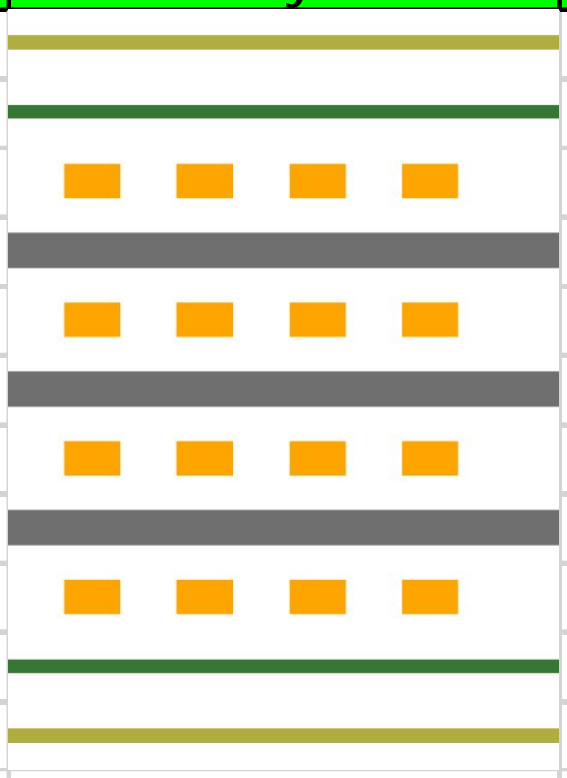
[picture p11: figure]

1 | | Top Overlay | | 0mm
2 | | Top Solder | SM-001 | 0.0254mm | 4 #FF008000
3 | | Top Signal | CF-004 | 0.035mm
4 | | Dielectric 1 | PP-017 | 0.12mm | 4.3
5 | | Solid GND | CF-004 | 0.035mm
6 | | Dielectric 3 | Core-039 | 1.2mm | 4.8
7 | | PWR | CF-004 | 0.035mm
8 | | Dielectric 5 | PP-017 | 0.12mm | 4.3
9 | | Bottom GND | CF-004 | 0.035mm
10 | | Bottom Solder | SM-001 | 0.0254mm | 4 #FF008000
11 | | Bottom Overlay | | 0mm
| Height : 1.6308mm

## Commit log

2026-06-18 added schematic and structure of the PCB
2026-06-18 compiled a list of BOM
    [Bill of Materials-111.xlsx]
2026-06-18 added file fabrication
    [Bill of Materials-111.xlsx]
2026-06-20 Update and rename technical-design.md to ADC block.md
2026-06-20 Update ADC block.md
2026-07-09 README: add STM32F103C8T6, firmware architecture and development plan
2026-07-09 docs: replace LTC2954 with discrete latch, add lessons-learned
    - MAIN block.md: updated pin map (PB1->PB3), replaced LTC2954 section
    with discrete latch description (AO3401A + BSS138 + BAT54C)
    - Lesson-learned/lessons-learned.md: created, first entry on LTC2954
    - Removed empty Lesson-learned/file
